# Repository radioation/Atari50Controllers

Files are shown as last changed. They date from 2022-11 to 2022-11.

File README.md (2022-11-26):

# Overview
I started working on this after printing out Mike Mika's [Xbox paddle adapter](https://www.thingiverse.com/digitaleclipse/designs)
for the "Atari 50: The Anniversary Celebration".   I realized I still had some 
old Atari 800 controllers and thought it might be fun to learn
how to use an Arduino Leonardo as a Joystick, Keyboard, and Mouse.

While working on this, I discovered there are already several other 
projects and products that adapt Atari 8-bit controllers to PC.  So it's probably 
easier fto just buy an existing adapter, but I do this sort of thing for fun.
I've been meaning to make custom game controllers for a while now. So this is 
a nice, easy learning exercise.

This project uses an knockff Leonardo and Matthew Heironimus's 
[Arduino Joystick Library](https://github.com/MHeironimus/ArduinoJoystickLibrary/tree/version-2.0)
and the Arduino [Keyboard and Mouse](https://docs.arduino.cc/built-in-examples/usb/KeyboardAndMouseControl)
libraries.   

## CX30 Paddle Controllers
Each paddle controller has a single fire button and a 1 MΩ potentiometer 
with just the wiper and one resistive terminal connected.  I originally 
used the voltage divider described
[here](https://www.circuitbasics.com/arduino-ohm-meter/) to estimate the 
rotation of the paddle knob.   One problem with using the voltage divider
was the paddle positions affected each others readings.   To address this,
I've switched to checking the charging time of an
[RC circuit](https://www.icode.com/analog-to-digital-conversion-with-rc-circuit-in-microcontroller-projects/).   
I alternate reading the first and second paddle which seems to eliminate 
the interference. 

I've noticed some problems with this method.  Each paddle has a different 
estimated maximum value.   It doesn't seem to affect gameplay much.
Another problem is the paddles don't automatically return to a center position. 
So the sketch may continously send left or right signals while you're navigating 
your game menu.   

## CX22  Trackball Controller
My sketch is based on the code found [here](https://jeffpiepmeier.blogspot.com/2016/08/vintage-atari-cx22-trak-ball-with-usb.html). 
The trackball controller should be set to _trackball_ mode but can also 
function as a joystick.

When in trackball mode, the CX22 figures out both the X and Y direction 
and rotation speed of the trackball for you.  I'm translating the trackball movements into 
mouse movements and using the button as a 'space-bar' press to match
the default fire setup in **Atari 50: 5200 _Missile Command_** 

If the trackball is set to `joytsick` mode, the sketch will act like 
a joystick instead of a mouse and keyboard.

## CX20  Driving Controller
The driving controller is a rotary encoder.  My implementation is based on
[this](https://howtomechatronics.com/tutorials/arduino/rotary-encoder-works-use-arduino/).
I added a counter to handle the rotation speed.

## CX40 Joystick
The Atari joystick controller is very simple.  It has 4 switches that pull down pins 1-4 of
the Atari DE9 port a fire button that pulls down pin 6.  

# The Circuit
This circuit can be found
[here](https://github.com/radioation/Atari50Controllers/blob/master/images/combined.pdf).
It can handle all 4 controller types.   The images folder also has simplified circuits that handle the 
paddle, driving, or trackball/joystick controllers individually.   The sketch should work with any
of them.

THe circuit lists 5 switches.  SW1, SW2, and SW3 are extra game controller buttons. These were 
added to support games that use more than one button.  These buttons are optional if you only
play games that use one button.  SW4 is a rocker switch.  It's used to center the paddle joystick 
output.  SW5 is is a reset button and optional.

The sketch can automatically detect the type of controller attached.   I based my detection on Control Freak's
description at [hackaday.io](https://hackaday.io/project/170908-control-freak/log/176711-atariing).    
It's not exactly the same.  I don't  have an Atari keypad and they don't mention the trackball controller.  
My sketch will first check for a valid paddle value.  If a paddle isn't detected, the sketch checks the 
joystick direction pins to determine what type of controller is attached.   If LEFT and RIGHT pins are detected 
simultaneously, the controller is a trackball controller.  If UP and DOWN are detected simultaneously, 
it's a driving controller.  If only one direction is detected, it's a joystick.

# Usage
Plug your Atari controller into the DE9 port on the Leonardo and connect the Leonardo to your PC's USB port.  
Move the controller around a bit to let the sketch determine what type of controller is connected.

If you have a paddle controller or joystick controller, the sketch will act like a USB 
Joystick.   The buttons will be mapped to joystick buttons. The paddle controllers will 
only affect the X axis of the joystick.  The second paddle controller will be mapped 
to a second USB joystick.  

If you have a trackball or driving controler, the sketch will act like a Keyboard and 
Mouse.  Based on the games I've played in Atari50, I mapped the fire button to 
the `Spacebar`.  The three other buttons are mapped to the `A`, `B`, and `C` keys.
You can either alter the sketch or remap the controls in Atari 50.

If you want to change the controller, swap it out and press the RESET button on the 
Arduino.  This will restart controller detection.

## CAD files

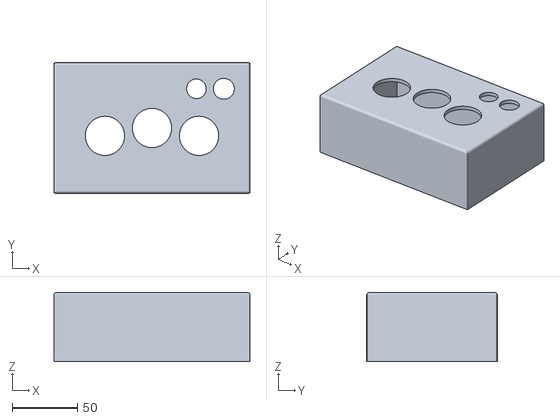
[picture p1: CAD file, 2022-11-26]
cad/Atari50_case-Body.stl
150.0 x 100.0 x 53.0

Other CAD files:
cad/Atari50_case.FCStd

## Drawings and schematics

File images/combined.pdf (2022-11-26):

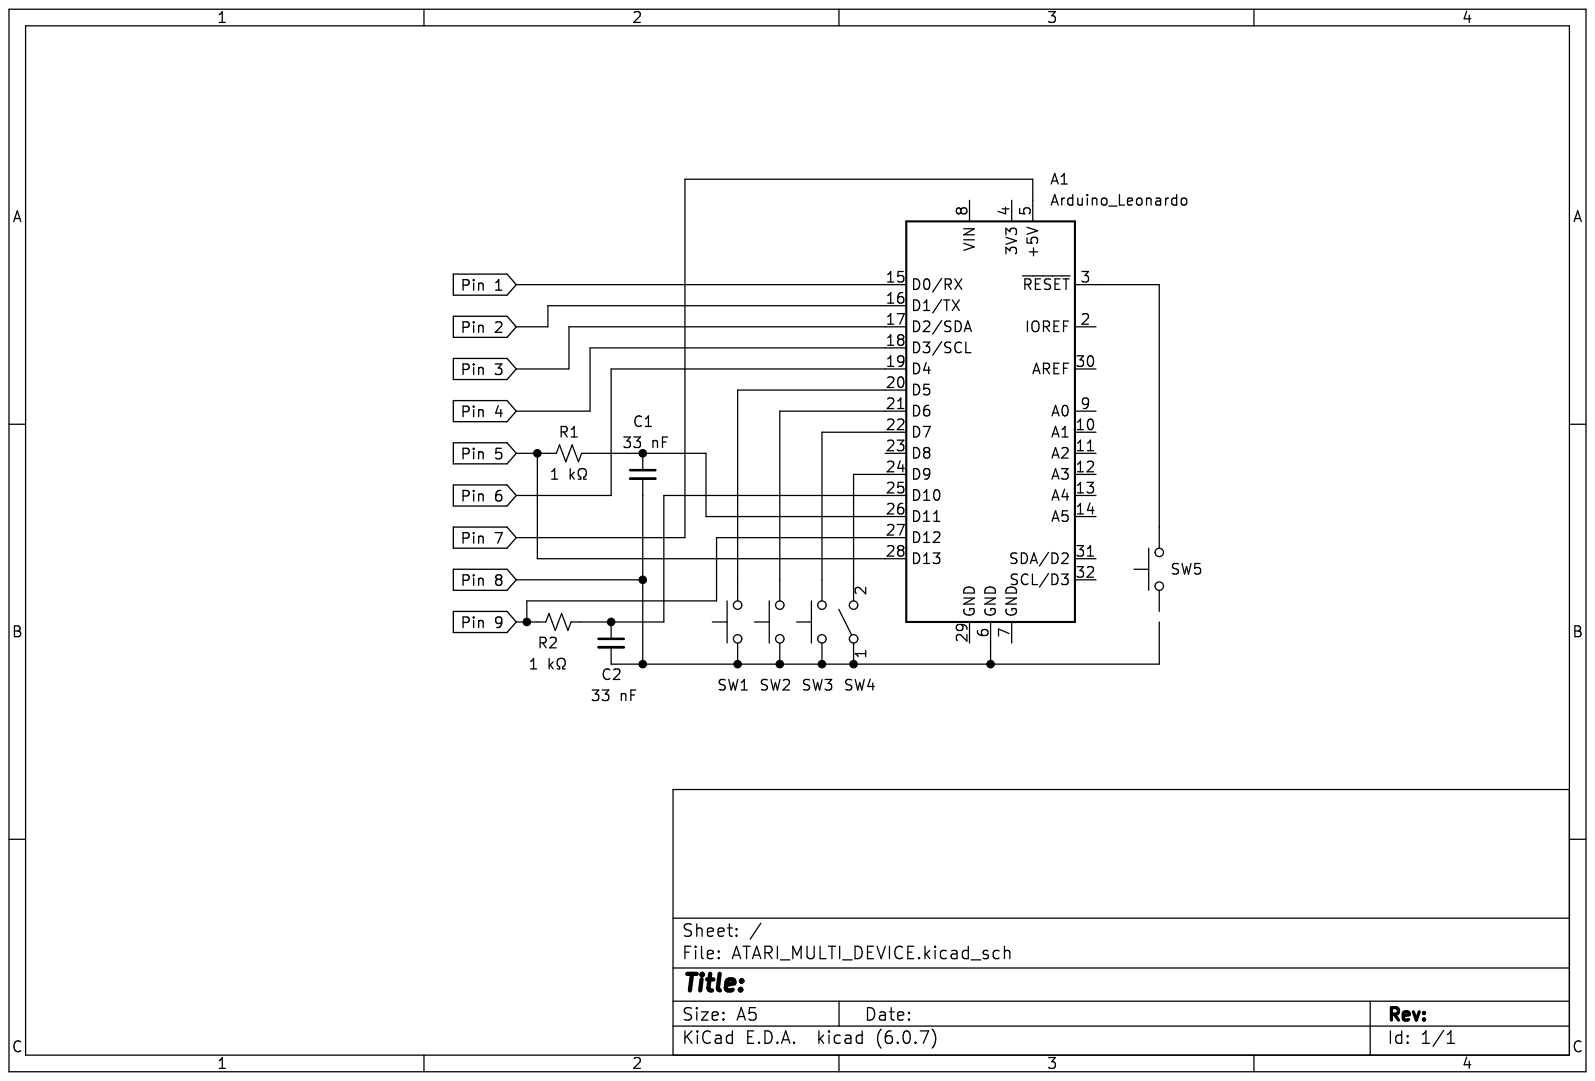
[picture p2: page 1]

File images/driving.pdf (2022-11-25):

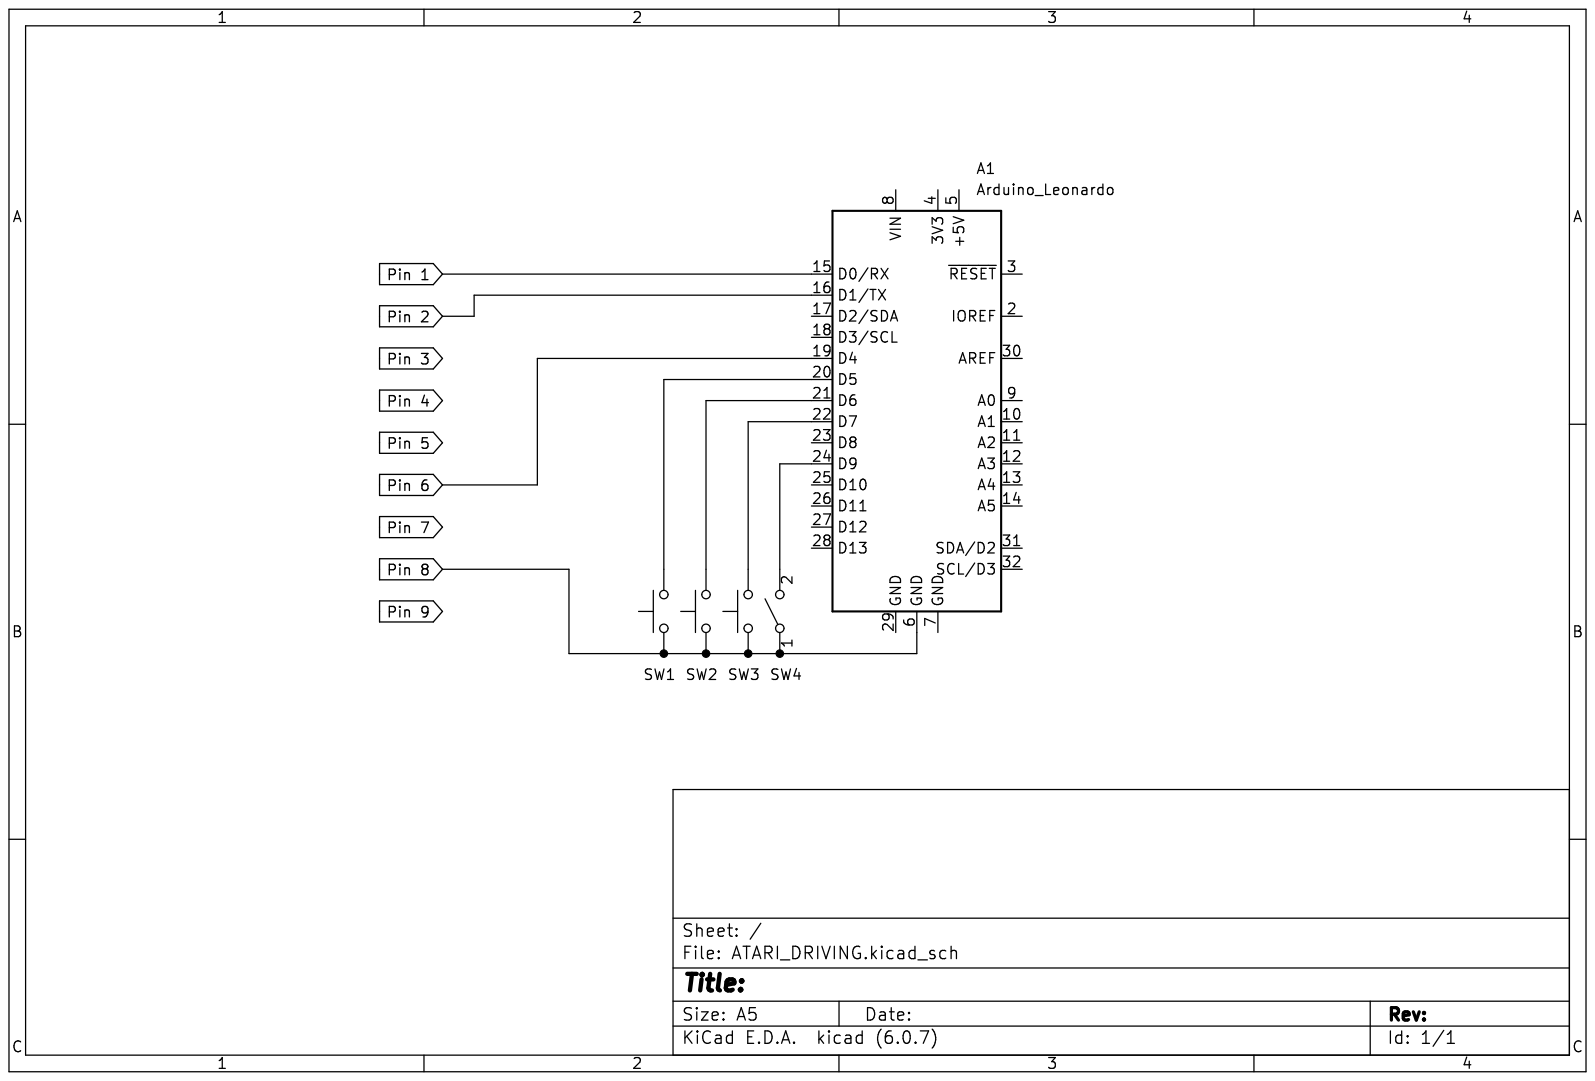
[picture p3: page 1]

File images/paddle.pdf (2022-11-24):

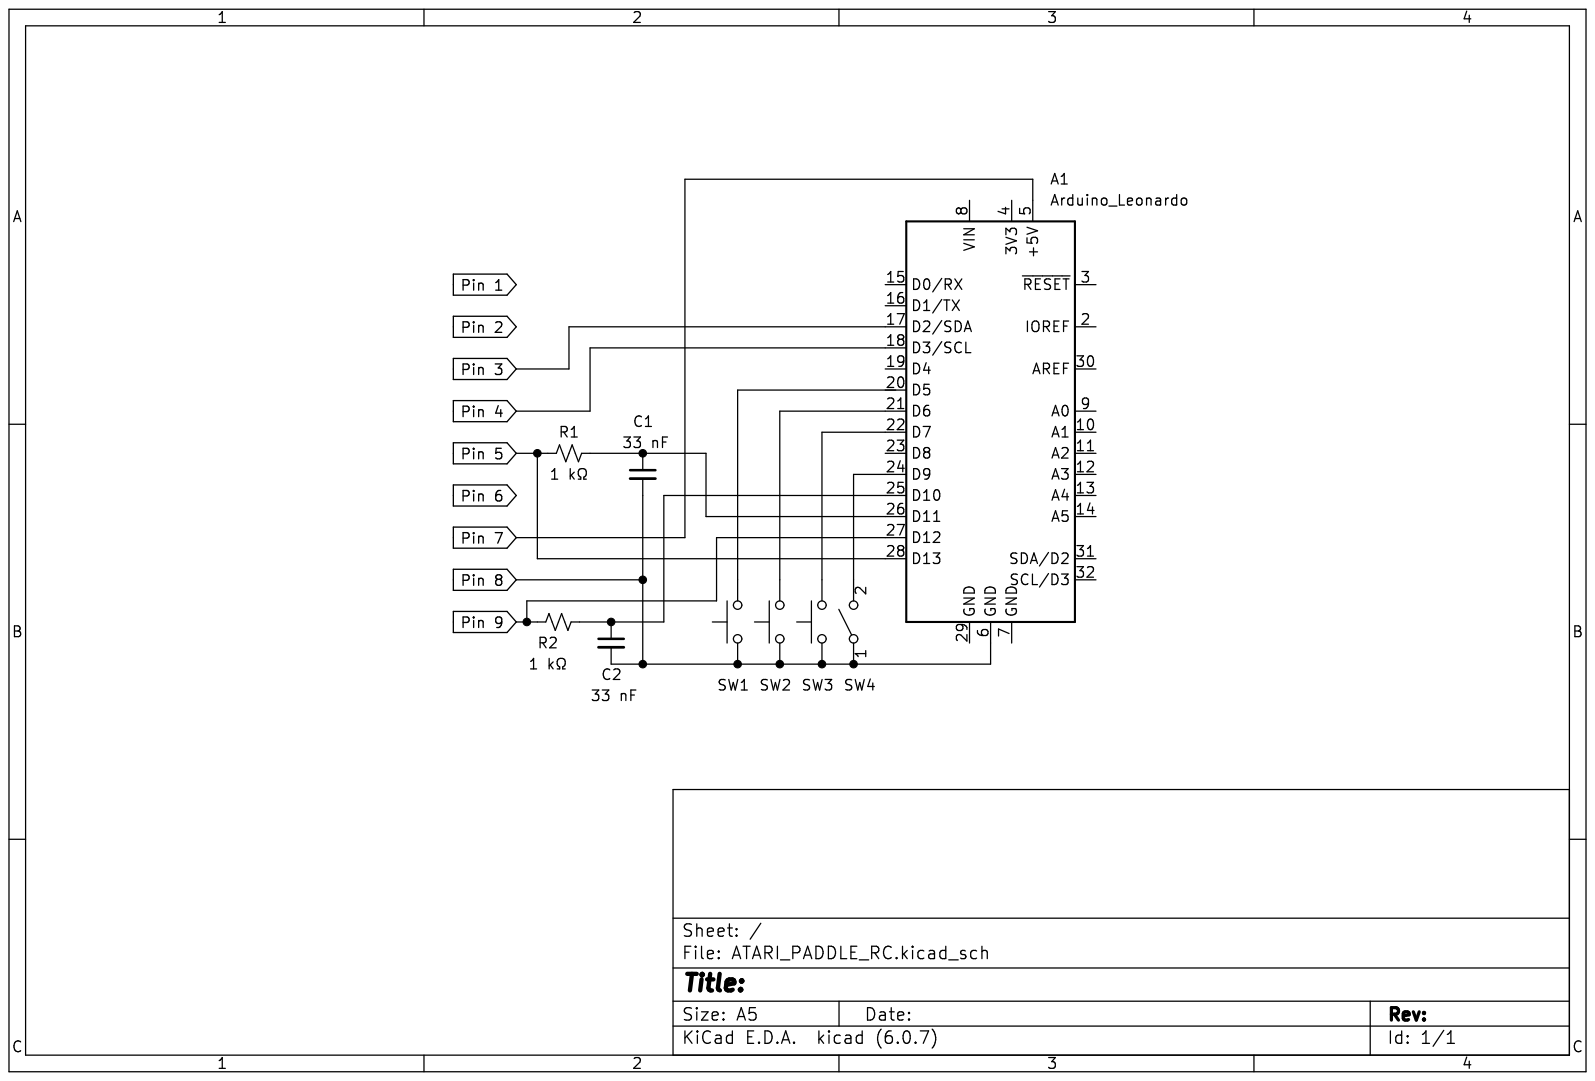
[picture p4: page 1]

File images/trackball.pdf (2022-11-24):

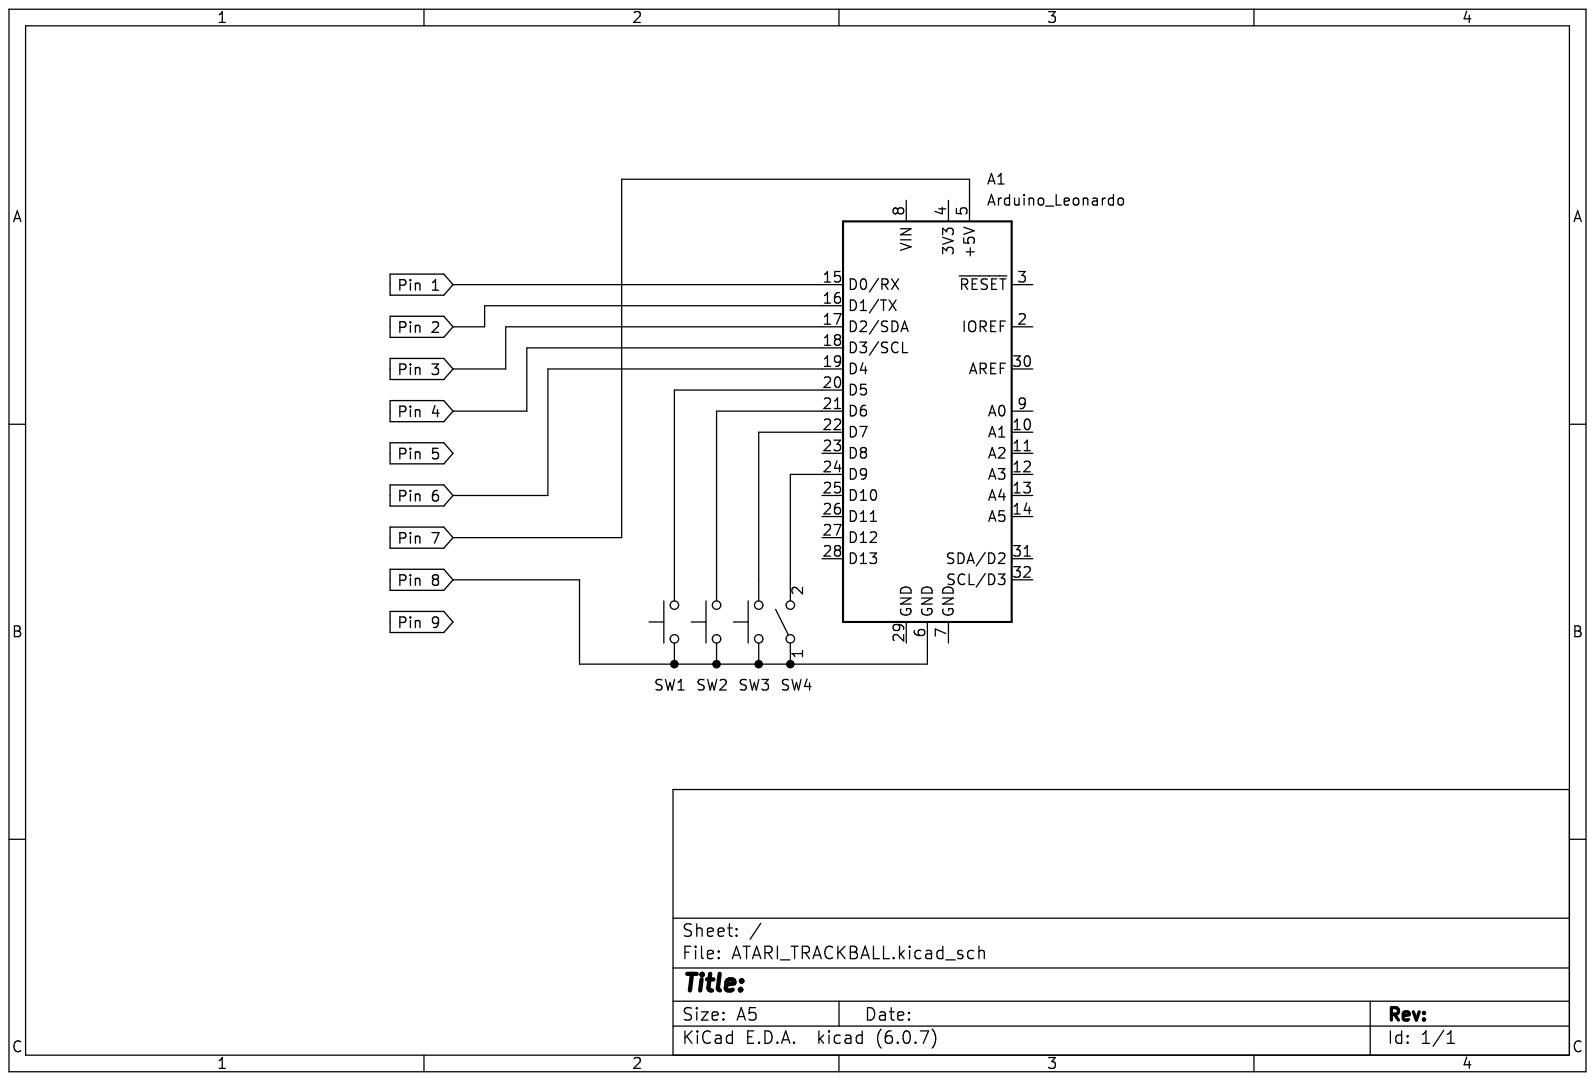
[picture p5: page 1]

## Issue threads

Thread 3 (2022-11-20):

Fix menu navigation when a paddle controller is connected

radioation, 2022-11-20:
Paddle controller interferes with game menu navigation and selection.   Add a switch to turn joystick position messages on and off.

radioation, 2022-11-24:
Added code to check if switch on pin digital I/O pin is open or closed.   Sketch will center joystick when open.  If closed, the sketch will calculate a position and send it as the X-axis value.

Closed 2022-11-24.

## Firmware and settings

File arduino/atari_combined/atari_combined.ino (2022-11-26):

#include <Joystick.h>
#include "Mouse.h"
#include "Keyboard.h"

// Paddle I/O Pins
const byte PADDLE_1_CAP_PIN_9 = 10;  // read from cap
const byte PADDLE_2_CAP_PIN_5 = 11;
const byte PADDLE_1_POT_PIN_9 = 12;  // discharge at resistor
const byte PADDLE_2_POT_PIN_5 = 13;
const byte PADDLE_1_BTN_PIN_3 = 2;
const byte PADDLE_2_BTN_PIN_4 = 3;
const byte PADDLES_ACTIVE = 9;  // use this to turn switch on/off
// paddle values
unsigned long startTime;
unsigned long elapsedTime;
float paddle1 = 0;
float paddle2 = 0;

int lastButtonState1 = 0;
int lastButtonState2 = 0;

const float paddle1min = 0.66f;
const float paddle2min = 0.66f;

// Driving I/O Pins
const byte DRIVING_PIN_1 = 0;  // also used by trackball controller
const byte DRIVING_PIN_2 = 1;  // also used by trackball controller
const byte BUTTON_PIN_6 = 4;   // also used by trackball controller
// driving values
byte drivingPin1State = LOW;
byte lastDrivingPin1State = LOW;
byte drivingPin2State = LOW;
byte lastDrivingPin2State = LOW;
byte currentRotationDir = 0;
byte lastRotationDir = 0;

int drivingCounter = 0;
int drivingScale = 10;

// Trackball I/O Pins
const byte JOYSTICK_TRACKBALL_PIN_1 = 0;  // also used by driving controller
const byte JOYSTICK_TRACKBALL_PIN_2 = 1;  // also used by driving controller
const byte JOYSTICK_TRACKBALL_PIN_3 = 2;
const byte JOYSTICK_TRACKBALL_PIN_4 = 3;
// const byte TRACKBALL_BUTTON_PIN_6 = 4;  // also used by driving controller
// trackball values
const int trackballScaleX = 7;
const int trackballScaleY = 7;

int trackballDirectionX = LOW;
int trackballMotionX = LOW;
int trackballDirectionY = LOW;
int trackballMotionY = LOW;




// extra buttons/switches
const byte EXTRA_BUTTON_A = 5;
const byte EXTRA_BUTTON_B = 6;
const byte EXTRA_BUTTON_C = 7;
int lastButtonStateA = 0;
int lastButtonStateB = 0;
int lastButtonStateC = 0;


const byte ZERO_JOYSTICK_SWITCH = 9;

enum CONTROLLER_TYPE { UNKNOWN_CTRL,
                       PADDLE_CTRL,
                       DRIVING_CTRL,
                       TRACKBALL_CTRL,
                       JOYSTICK_CTRL };
CONTROLLER_TYPE controllerType = UNKNOWN_CTRL;

// setup joystick
Joystick_ Joystick(JOYSTICK_DEFAULT_REPORT_ID,
                   JOYSTICK_TYPE_JOYSTICK,
                   4, 0,                  // Button Count, Hat Switch Count
                   true, true, false,     // X and Y, but no Z Axis
                   false, false, false,   // No Rx, Ry, or Rz
                   false, false,          // No rudder or throttle
                   false, false, false);  // No accelerator, brake, or steering

Joystick_ Joystick2(JOYSTICK_DEFAULT_REPORT_ID + 1,
                    JOYSTICK_TYPE_JOYSTICK,
                    2, 0,                  // Button Count, Hat Switch Count
                    true, true, false,     // X and Y, but no Z Axis
                    false, false, false,   // No Rx, Ry, or Rz
                    false, false,          // No rudder or throttle
                    false, false, false);  // No accelerator, brake, or steering

void setup() {
  // setup paddles
  pinMode(PADDLE_1_CAP_PIN_9, INPUT);
  pinMode(PADDLE_2_CAP_PIN_5, INPUT);
  pinMode(PADDLE_1_POT_PIN_9, OUTPUT);
  pinMode(PADDLE_2_POT_PIN_5, OUTPUT);
  pinMode(PADDLE_1_BTN_PIN_3, INPUT_PULLUP);
  pinMode(PADDLE_2_BTN_PIN_4, INPUT_PULLUP);
  pinMode(PADDLES_ACTIVE, INPUT_PULLUP);

  // setup driving and trackball pins
  pinMode(DRIVING_PIN_1, INPUT_PULLUP);
  pinMode(DRIVING_PIN_2, INPUT_PULLUP);
  pinMode(JOYSTICK_TRACKBALL_PIN_3, INPUT_PULLUP);
  pinMode(JOYSTICK_TRACKBALL_PIN_4, INPUT_PULLUP);
  pinMode(BUTTON_PIN_6, INPUT_PULLUP);

  // setup shared buttons
  pinMode(EXTRA_BUTTON_A, INPUT_PULLUP);
  pinMode(EXTRA_BUTTON_B, INPUT_PULLUP);
  pinMode(EXTRA_BUTTON_C, INPUT_PULLUP);
  pinMode(ZERO_JOYSTICK_SWITCH, INPUT_PULLUP);

  // Initialize Joystick Library                            
  Joystick.begin();
  Joystick.setXAxisRange(-127, 127);
  Joystick.setYAxisRange(-127, 127);
  Joystick.setXAxis(0.0f);
  Joystick2.begin();
  Joystick2.setXAxisRange(-127, 127);
  Joystick2.setYAxisRange(-127, 127);
  Joystick2.setXAxis(0.0f);

  // initialize Mouse and Keyboard
  Mouse.begin();
  Keyboard.begin();
}

void detectControllers() {

  // just need to check one paddle for decent value
  pinMode(PADDLE_1_POT_PIN_9, OUTPUT);
  digitalWrite(PADDLE_1_POT_PIN_9, LOW);
  delay(5);
  pinMode(PADDLE_1_POT_PIN_9, INPUT);
  delay(20);
  auto isPaddle = digitalRead(PADDLE_1_CAP_PIN_9);
  if (isPaddle == HIGH) {
    controllerType = PADDLE_CTRL;
    return;
  }

  // trackball and driving controllers can both be UP|DOWN at the same time/
  // Read all 4 pins a whole bunch of times, if LEFT|RIGHT even occurse once,
  // it's a trackball.
  for (int i = 0; i < 32767; ++i) {  // 32767 might be excessive.
    auto pin1 = digitalRead(DRIVING_PIN_1);
    auto pin2 = digitalRead(DRIVING_PIN_2);
    auto pin3 = digitalRead(JOYSTICK_TRACKBALL_PIN_3);
    auto pin4 = digitalRead(JOYSTICK_TRACKBALL_PIN_4);
    if (pin4 == LOW && pin3 == LOW) {  // left/right is trackball ctr
      controllerType = TRACKBALL_CTRL;
      return;  // exit out, it's a trackball.
    }
    if (pin1 == LOW && pin2 == LOW) {  // could be driving or trackball, but go with DRIVING
      controllerType = DRIVING_CTRL;
    }
    if (controllerType == UNKNOWN_CTRL) {
      // if only one is low, it might be a joystick
      if (pin1 + pin2 + pin3 + pin4 == 3) {
        controllerType = JOYSTICK_CTRL;
      }
    }
  }
}

void updatePaddles() {
  for (int i = 0; i < 2; ++i) {
    pinMode(PADDLE_1_POT_PIN_9 + i, OUTPUT);    // set discharge pin to output
    digitalWrite(PADDLE_1_POT_PIN_9 + i, LOW);  // set discharge pin LOW
    delay(4);                                   // 1 seemed sufficient discharge time in tests but 4 should sufficient the hell out of it.
    pinMode(PADDLE_1_POT_PIN_9 + i, INPUT);
    startTime = micros();
    while (digitalRead(PADDLE_1_CAP_PIN_9 + i) < 1)
      ;
    if (i == 0) {
      paddle1 = micros() - startTime;
    } else {
      paddle2 = micros() - startTime;
    }
  }

  // check if PADDLES_ACTIVE switch is close.
  if (digitalRead(PADDLES_ACTIVE) == LOW) {
    // scale and translate paddle readings.  (This could still use a proper calibration step)
    float joy1_x = -(127.0f * 2.0f * (paddle1 / 9000.0f) - 127.0f);
    Joystick.setXAxis(joy1_x);
    float joy2_x = -(127.0f * 2.0f * (paddle2 / 9000.0f) - 127.0f);
    Joystick2.setXAxis(joy2_x);
  } else {
    // center the joystick output when deactivated.
    Joystick.setXAxis(0);
    Joystick2.setXAxis(0);
  }

  // Set buttons
  int currentButtonState = digitalRead(PADDLE_1_BTN_PIN_3);
  if (currentButtonState != lastButtonState1) {
    Joystick.setButton(0, !currentButtonState);
    lastButtonState1 = currentButtonState;
  }

  currentButtonState = digitalRead(PADDLE_2_BTN_PIN_4);
  if (currentButtonState != lastButtonState2) {
    Joystick2.setButton(0, !currentButtonState);
    lastButtonState2 = currentButtonState;
  }
}

void updateExtraPaddleButtons() {
  // Set buttons
  int currentButtonState = digitalRead(EXTRA_BUTTON_A);
  if (currentButtonState != lastButtonStateA) {
    Joystick.setButton(1, !currentButtonState);
    lastButtonStateA = currentButtonState;
  }

  currentButtonState = digitalRead(EXTRA_BUTTON_B);
  if (currentButtonState != lastButtonStateB) {
    Joystick.setButton(2, !currentButtonState);
    lastButtonStateB = currentButtonState;
  }

  currentButtonState = digitalRead(EXTRA_BUTTON_C);
  if (currentButtonState != lastButtonStateC) {
    Joystick2.setButton(1, !currentButtonState);
    lastButtonStateC = currentButtonState;
  }
}

void updateTrackball() {
  // logic from http://jeffpiepmeier.blogspot.com/2016/08/vintage-atari-cx22-trak-ball-with-usb.html
  int xold = trackballMotionX;
  int yold = trackballMotionY;

  trackballDirectionX = digitalRead(JOYSTICK_TRACKBALL_PIN_1) * 2 - 1;
  trackballMotionX = digitalRead(JOYSTICK_TRACKBALL_PIN_2);
  trackballDirectionY = digitalRead(JOYSTICK_TRACKBALL_PIN_3) * 2 - 1;
  trackballMotionY = digitalRead(JOYSTICK_TRACKBALL_PIN_4);

  if (trackballMotionX != xold) {
    Mouse.move(trackballDirectionX * trackballScaleX, 0);
  }

  if (trackballMotionY != yold) {
    Mouse.move(0, trackballDirectionY * trackballScaleY);
  }

  // Atari 50 defaults to spacebar for fire button.
  int currentButtonState = digitalRead(BUTTON_PIN_6);
  if (currentButtonState != lastButtonState1) {
    if (!currentButtonState) {
      Keyboard.press(' ');
    } else {
      Keyboard.release(' ');
    }
    lastButtonState1 = currentButtonState;
  }
}


void updateDriving() {
  currentRotationDir = 0;
  drivingPin1State = digitalRead(DRIVING_PIN_1);
  drivingPin2State = digitalRead(DRIVING_PIN_2);

  if (drivingPin2State != lastDrivingPin2State) {
    currentRotationDir = (drivingPin2State - lastDrivingPin2State) * (drivingPin1State ? +1 : -1);

  } else if (drivingPin1State != lastDrivingPin1State) {
    currentRotationDir = (drivingPin1State - lastDrivingPin1State) * (drivingPin2State ? -1 : +1);
  }


  if (currentRotationDir != 0) {

    lastDrivingPin1State = drivingPin1State;
    lastDrivingPin2State = drivingPin2State;

    if (currentRotationDir == lastRotationDir) {
      drivingCounter++;
    } else {
      drivingCounter = 1;
    }

    // Mouse.move has a maximum step size of 127.
    int delta = drivingCounter * drivingScale;
    if (delta < 128) {
      Mouse.move(currentRotationDir * delta, 0);
    } else {
      while (delta > 128) {
        Mouse.move(currentRotationDir * 127, 0);
        delta -= 127;
      }
      Mouse.move(currentRotationDir * delta, 0);
    }

    lastRotationDir = currentRotationDir;
  } else {
    drivingCounter = 1;
  }

  // Atari 50 defaults to spacebar for fire button with mouse controls.

  int currentButtonState = digitalRead(BUTTON_PIN_6);
  if (currentButtonState != lastButtonState1) {
    if (!currentButtonState) {
      Keyboard.press(' ');
    } else {
      Keyboard.release(' ');
    }
    lastButtonState1 = currentButtonState;
  }
}

void updateExtraButtons() {

  // Set button keypresses
  int currentButtonState = digitalRead(EXTRA_BUTTON_A);
  if (currentButtonState != lastButtonStateA) {
    if (!currentButtonState) {
      Keyboard.press(97);
    } else {
      Keyboard.release(97);
    }
    lastButtonStateA = currentButtonState;
  }

  currentButtonState = digitalRead(EXTRA_BUTTON_B);
  if (currentButtonState != lastButtonStateB) {
    if (!currentButtonState) {
      Keyboard.press(98);
    } else {
      Keyboard.release(98);
    }
    lastButtonStateB = currentButtonState;
  }

  currentButtonState = digitalRead(EXTRA_BUTTON_C);
  if (currentButtonState != lastButtonStateC) {
    if (!currentButtonState) {
      Keyboard.press(99);
    } else {
      Keyboard.release(99);
    }
    lastButtonStateC = currentButtonState;
  }
}

void updateJoystick() {
  auto up = digitalRead(DRIVING_PIN_1);
  auto down = digitalRead(DRIVING_PIN_2);
  auto left = digitalRead(JOYSTICK_TRACKBALL_PIN_3);
  auto right = digitalRead(JOYSTICK_TRACKBALL_PIN_4);
  int joy_x = 0;
  int joy_y = 0;
  if (up == LOW) {
    joy_y = -127;
  }
  if (down == LOW) {
    joy_y = 127;
  }
  if (left == LOW) {
    joy_x = -127;
  }
  if (right == LOW) {
    joy_x = 127;
  }
  Joystick.setXAxis(joy_x);
  Joystick.setYAxis(joy_y);

  // handle actual button
  int currentButtonState = digitalRead(BUTTON_PIN_6);
  if (currentButtonState != lastButtonState1) {
    Joystick.setButton(0, !currentButtonState);
    lastButtonState1 = currentButtonState;
  }
}

void updateExtraJoystickButtons() {

  // Set button keypresses
  int currentButtonState = digitalRead(EXTRA_BUTTON_A);
  if (currentButtonState != lastButtonStateA) {
    Joystick.setButton(1, !currentButtonState);
    lastButtonStateA = currentButtonState;
  }

  currentButtonState = digitalRead(EXTRA_BUTTON_B);
  if (currentButtonState != lastButtonStateB) {
    Joystick.setButton(2, !currentButtonState);
    lastButtonStateB = currentButtonState;
  }

  currentButtonState = digitalRead(EXTRA_BUTTON_C);
  if (currentButtonState != lastButtonStateC) {
    Joystick.setButton(3, !currentButtonState);
    lastButtonStateC = currentButtonState;
  }
}


void loop() {
  switch (controllerType) {
    case UNKNOWN_CTRL:
      {
        detectControllers();
        break;
      }
    case PADDLE_CTRL:
      {
        updatePaddles();
        updateExtraPaddleButtons();
        break;
      }
    case DRIVING_CTRL:
      {
        updateDriving();
        updateExtraButtons();
        break;
      }
    case TRACKBALL_CTRL:
      {
        updateTrackball();
        updateExtraButtons();
        break;
      }
    case JOYSTICK_CTRL:
      {
        updateJoystick();
        updateExtraJoystickButtons();
        break;
      }
  }
}

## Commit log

2022-11-15 adding basic circuits
2022-11-17 fixing trackball schematic
2022-11-17 fixing driving controller schematic
2022-11-19 updating paddles to use RC circuit
2022-11-19 adding first attempt at combined wiring
2022-11-24 working on combined sketch/circuits
2022-11-24 Paddle Joystick output will be centered when paddle switch is open
2022-11-24 Add code to handle more buttons
    Adding code to send joystick button or keyboard presses.
2022-11-24 Adding buttons to driving controller
2022-11-25 Fixing extra button B read
    [atari_combined.ino]
2022-11-26 Adding joystick detection and control functions. Fixing button logic.
    [atari_combined.ino]
2022-11-26 Updating circuit and adding CAD drawings used for extra joystick buttons
    [Atari50_case-Body.stl, Atari50_case.FCStd]
